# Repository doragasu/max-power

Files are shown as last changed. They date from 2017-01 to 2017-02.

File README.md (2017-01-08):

# max-power: Multi ATX Cross Power

This is just a dumb PCB that I designed to end with the big mess of wall adapters I have under my TV, powering two RaspberryPi boards, several hard disks, routers, a USB hub, an HDMI to optical splitter, and maybe something more I'm missing right now. The board provides the following outputs:

* 2x5V standby (USB-A, always ON)
* 4x5V (USB-A)
* 6x12V (Terminal blocks)
* 4x3.3V (Terminal blocks)

It also features a power button and a power LED.

## Usage

The board must be connected at least to an ATX power source (I use a very old 300W one) and to a Raspberry Pi (that will be always powered, I connect the one I use as home server). This RPi is connected to an internal ATX +5V_SB rail, so as long as the ATX PS is powered, so will be this RPi. To power ON/OFF all the power outputs (other than the +5V_SB ones), a small program on the RPi monitors:
* The power button on the board; and
* The network for specially crafted packets.

This way the PS can be switched ON/OFF either by pressing the power button, or by using an application (e.g. on a smartphone) to send power ON/OFF commands.

## Licenses

Footprints and 3D modules under `fp` directory, have been obtained from http://smisioto.no-ip.org/elettronica/kicad/kicad-en.htm, and are under GPLv3 license. All other hardware CAD files in this repository are licensed under the CERN OHL 1.2 license.

Software sources under this repository are licensed under the GPLv3+ license.

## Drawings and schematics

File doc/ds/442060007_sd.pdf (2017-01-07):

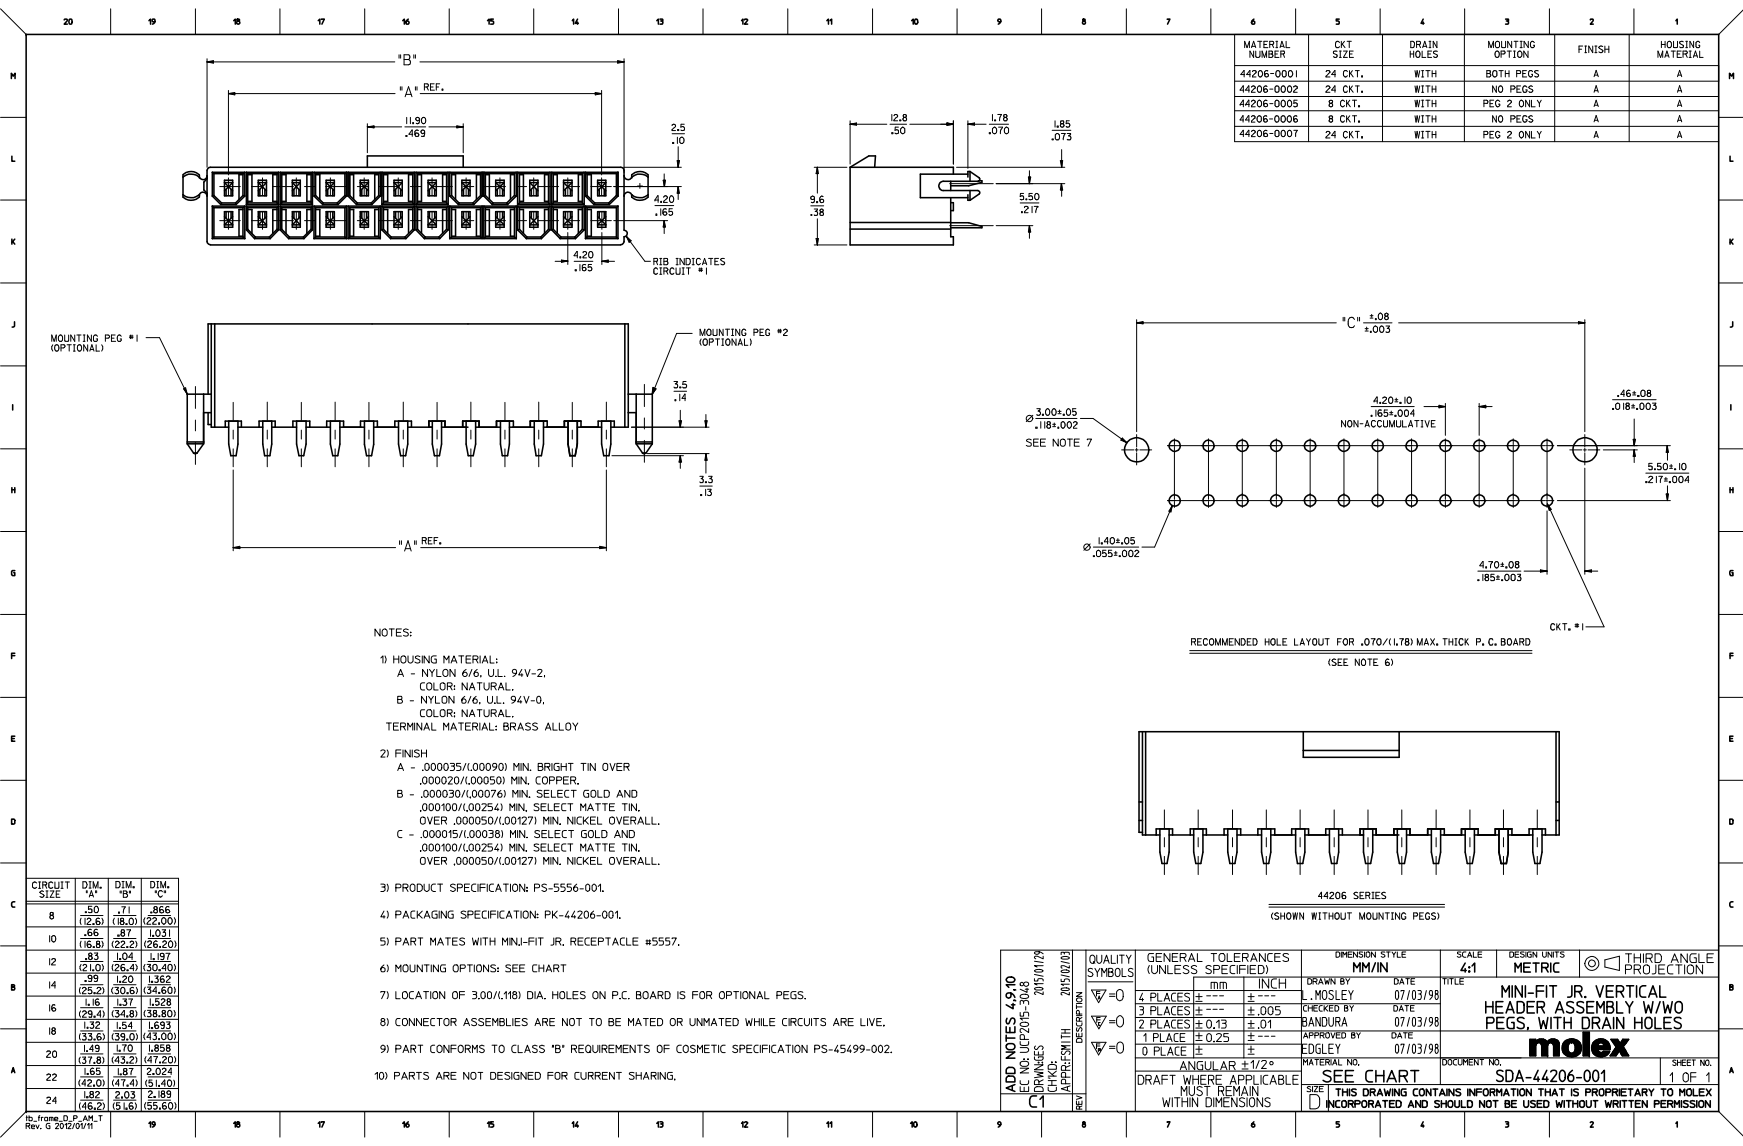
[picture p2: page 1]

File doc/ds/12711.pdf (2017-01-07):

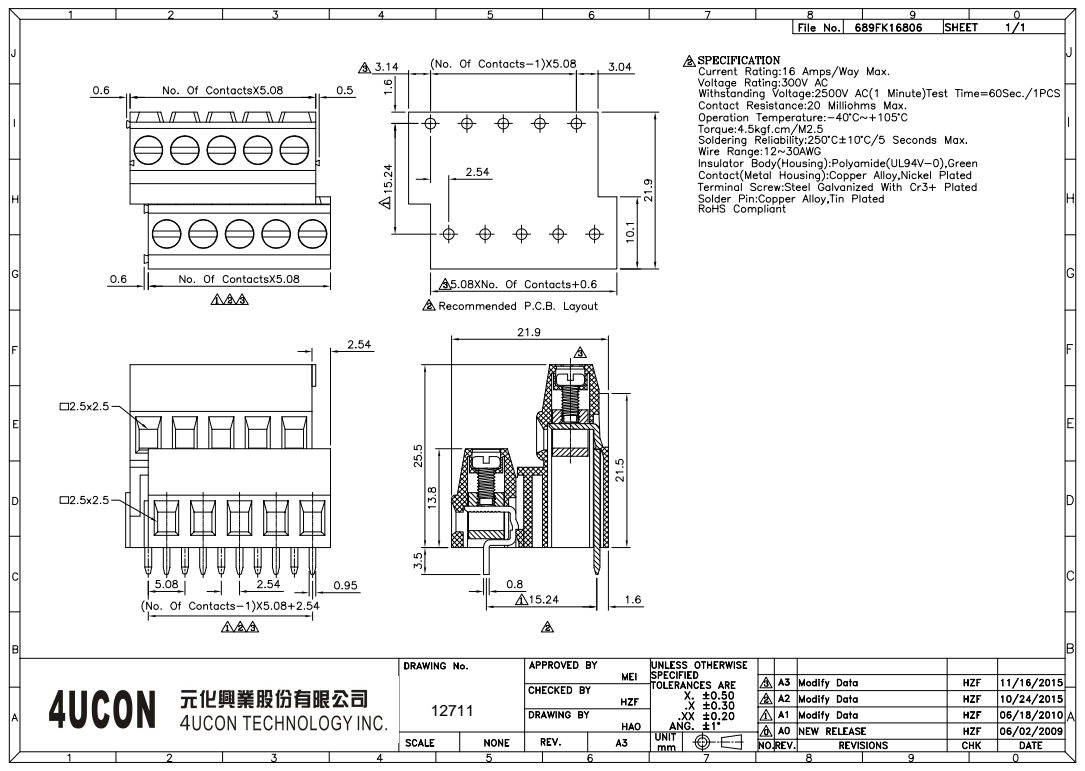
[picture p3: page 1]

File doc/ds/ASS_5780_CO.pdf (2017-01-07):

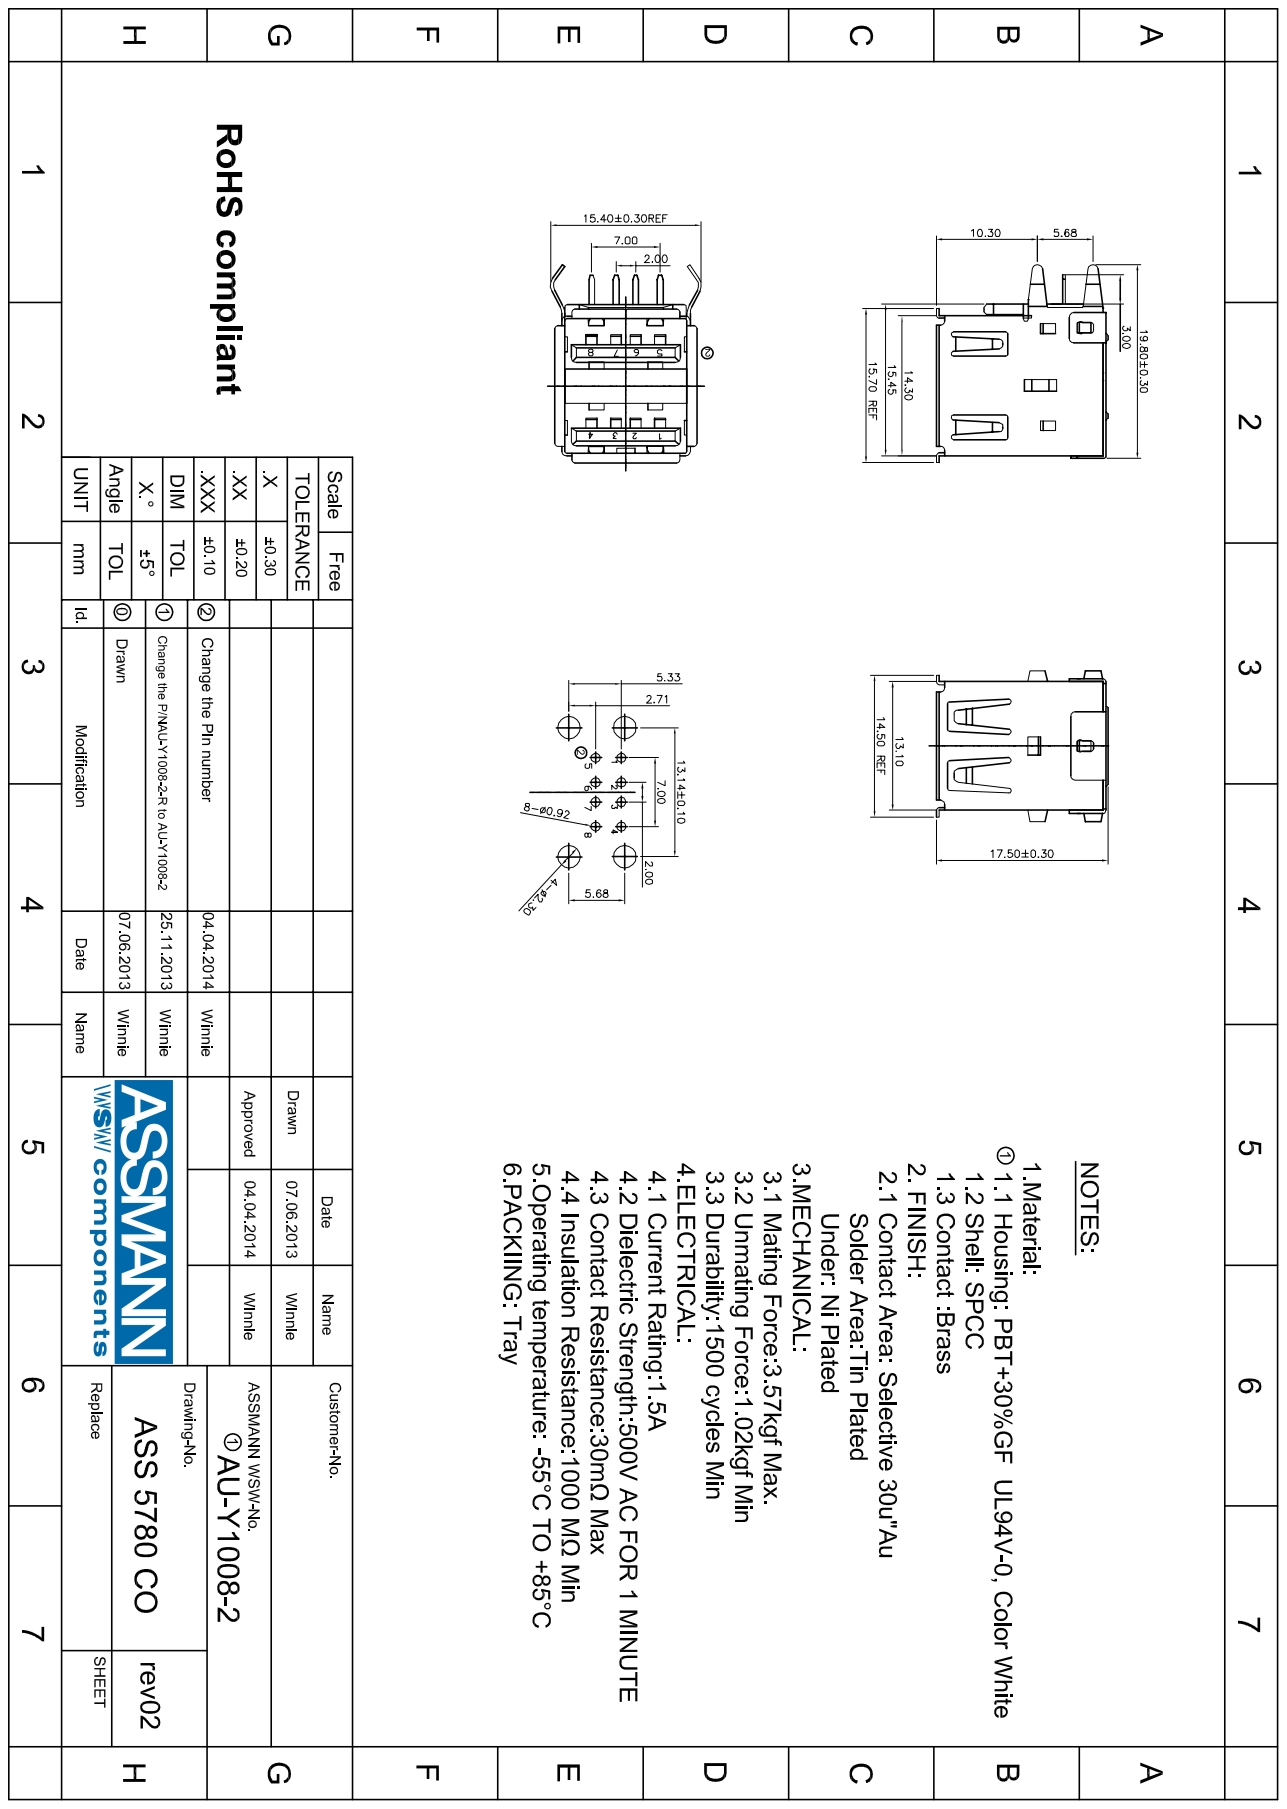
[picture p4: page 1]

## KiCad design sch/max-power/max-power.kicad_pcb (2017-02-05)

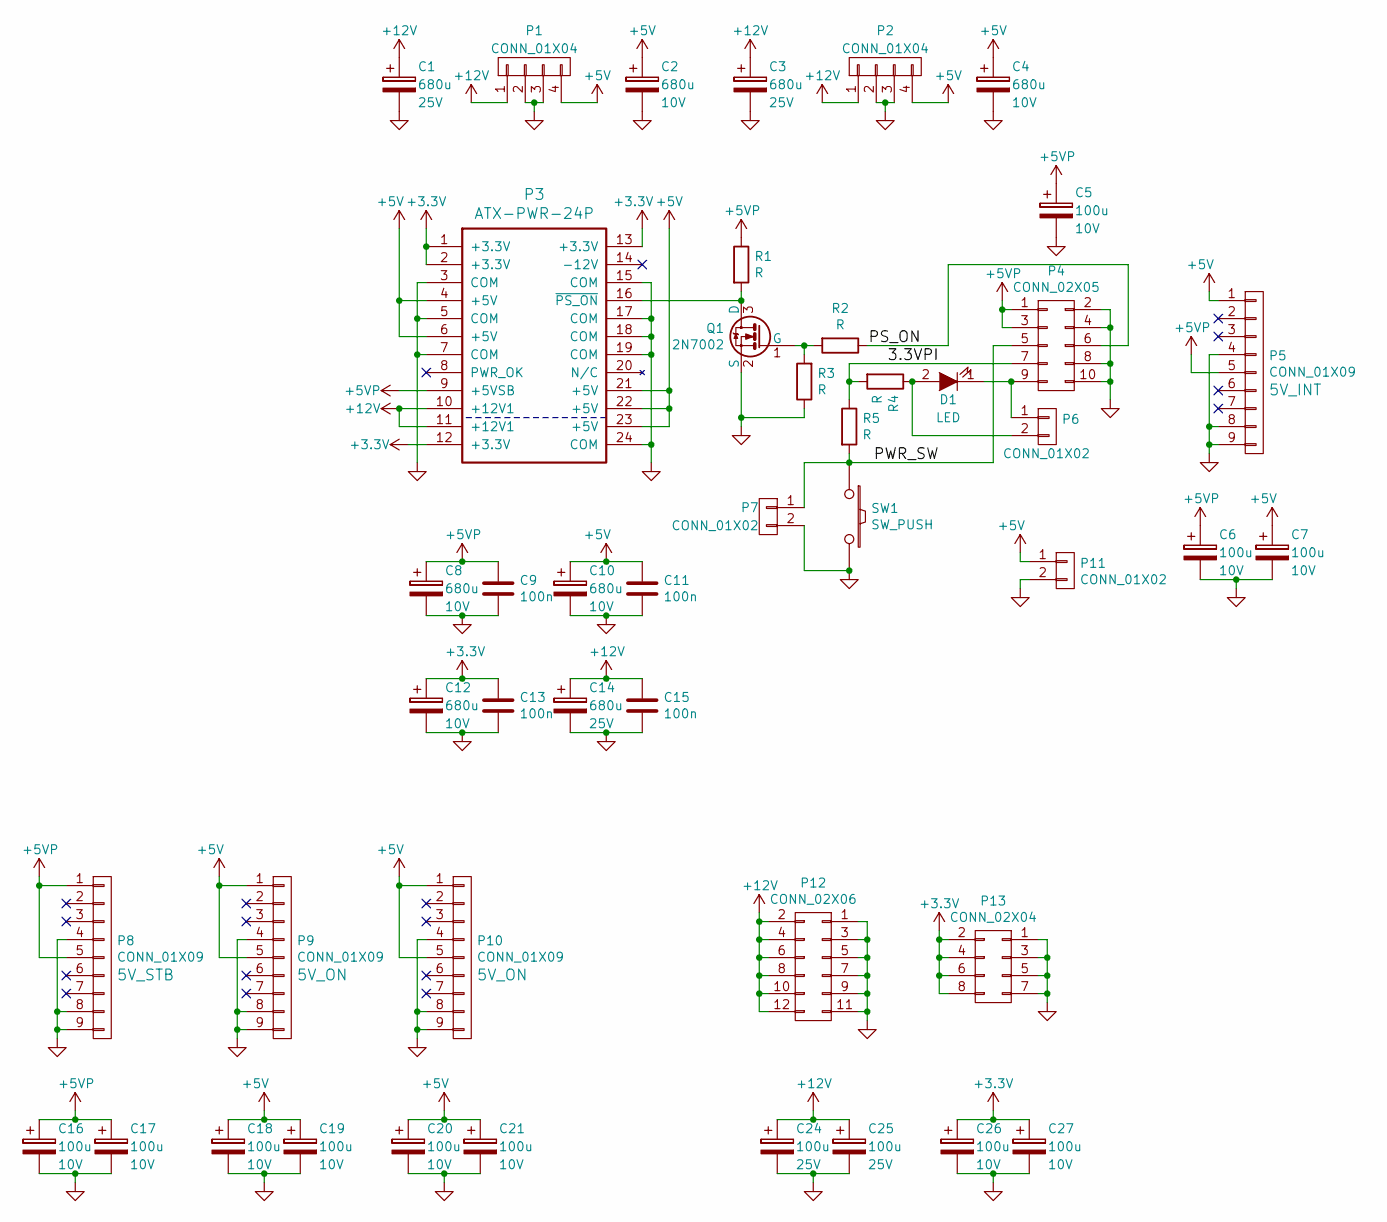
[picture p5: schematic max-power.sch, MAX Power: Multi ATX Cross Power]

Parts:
C1, C3, C14: 680u; C_Radial_D10_L13_P5; Rating 25V
C2, C4, C8, C10, C12: 680u; C_Radial_D10_L13_P5; Rating 10V
C5, C6, C7, C16, C17, C18, C19, C20, C21, C26, C27: 100u; C_Radial_D5_L11_P2; Rating 10V
C9, C11, C13, C15: 100n; C_0805
C24, C25: 100u; C_Radial_D5_L11_P2; Rating 25V
D1: LED; LED-5MM
P1, P2: CONN_01X04; conn_hdd_15-24-4449
P3: ATX-PWR-24P; ATX_PWR_CON
P4: CONN_02X05; IDC_Header_Straight_10pins
P5, P8, P9, P10: CONN_01X09; USB_A_STACKED
P6, P7: CONN_01X02; Socket_MOLEX-KK-RM2-54mm_Lock_2pin_straight
P11: CONN_01X02; Socket_MOLEX-KK-RM3-96mm_Lock_2pin_straight
P12: CONN_02X06; TERM_BLOCK_6x2_5.08
P13: CONN_02X04; TERM_BLOCK_4x2_5.08
Q1: 2N7002; SOT-23
R1, R2, R3, R4, R5: R; R_0805
SW1: SW_PUSH; SW_PUSH_SMALL

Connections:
+3V3: C12.1, C13.1, C26.1, C27.1, P3.1 (+3.3V), P3.2 (+3.3V), P3.12 (+3.3V), P3.13 (+3.3V), P13.2, P13.4, P13.6, P13.8
+5V: C2.1, C4.1, C7.1, C10.1, C11.1, C18.1, C19.1, C20.1, C21.1, P1.4, P2.4, P3.4 (+5V), P3.6 (+5V), P3.21 (+5V), P3.22 (+5V), P3.23 (+5V), P5.1, P9.1, P9.5, P10.1, P10.5, P11.1
+5VP: C5.1, C6.1, C8.1, C9.1, C16.1, C17.1, P3.9 (+5VSB), P4.1, P4.3, P5.5, P8.1, P8.5, R1.1
+12V: C1.1, C3.1, C14.1, C15.1, C24.1, C25.1, P1.1, P2.1, P3.10 (+12V1), P3.11 (+12V1), P12.2, P12.4, P12.6, P12.8, P12.10, P12.12
/3.3VPI: P4.7, R4.2, R5.1
/PS_ON: P4.6, R2.1
/PWR_SW: P4.5, P7.1, R5.2, SW1.1
GND: C1.2, C2.2, C3.2, C4.2, C5.2, C6.2, C7.2, C8.2, C9.2, C10.2, C11.2, C12.2, C13.2, C14.2, C15.2, C16.2, C17.2, C18.2, C19.2, C20.2, C21.2, C24.2, C25.2, C26.2, C27.2, P1.2, P1.3, P2.2, P2.3, P3.3 (COM), P3.5 (COM), P3.7 (COM), P3.15 (COM), P3.17 (COM), P3.18 (COM), P3.19 (COM), P3.24 (COM), P4.2, P4.4, P4.8, P4.10, P5.4, P5.8, P5.9, P7.2, P8.4, P8.8, P8.9, P9.4, P9.8, P9.9, P10.4, P10.8, P10.9, P11.2, P12.1, P12.3, P12.5, P12.7, P12.9, P12.11, P13.1, P13.3, P13.5, P13.7, Q1.2 (S), R3.1, SW1.2
unnamed: D1.1 (K), P4.9, P6.1
unnamed: D1.2 (A), P6.2, R4.1
unnamed: P3.16 (~PS_ON), Q1.3 (D), R1.2
unnamed: Q1.1 (G), R2.2, R3.2

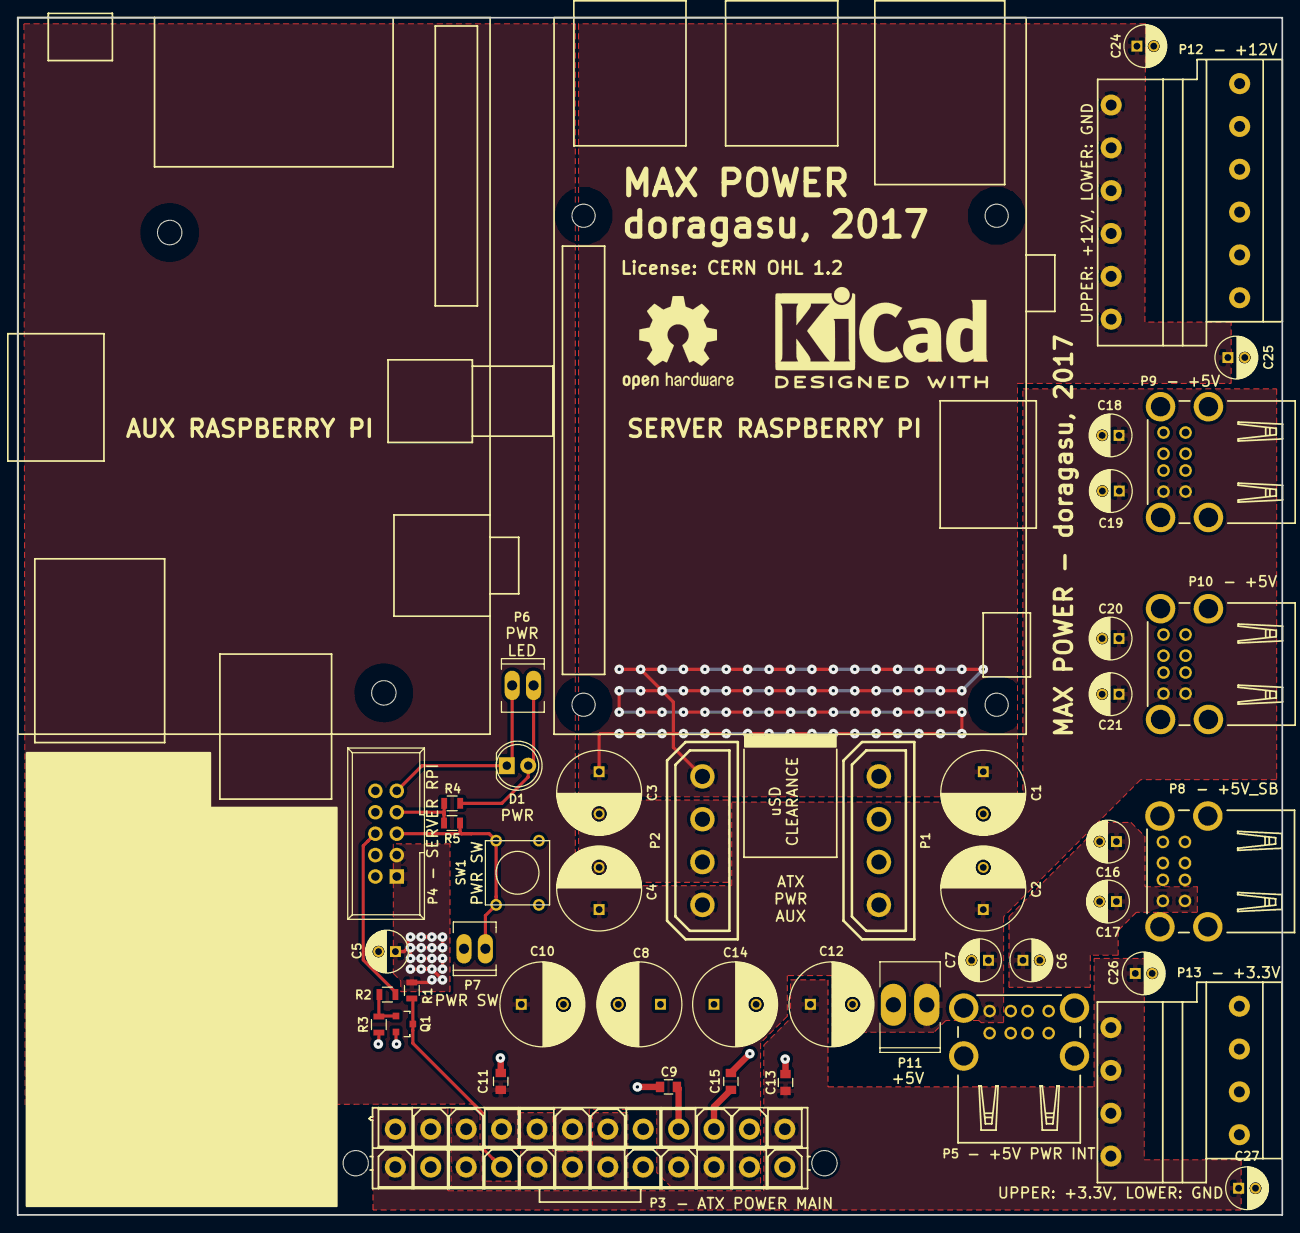
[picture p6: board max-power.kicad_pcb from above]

Board: 2 copper layers, 150.0 x 142.0 mm, 46 parts (0 on the bottom side), 12 nets.

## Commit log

2017-01-07 Added files.
    [max-power.kicad_pcb, max-power.sch]
2017-01-07 Initial placement of footprints.
    [max-power.kicad_pcb, max-power.sch]
2017-01-08 Routed PCB.
    [max-power.kicad_pcb, max-power.sch]
2017-01-08 Stetic changes.
    [max-power.kicad_pcb]
2017-02-05 Revision A finished, Gerbers sent to fab house.
    [max-power.kicad_pcb]

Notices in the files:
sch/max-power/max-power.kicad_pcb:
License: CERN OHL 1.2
